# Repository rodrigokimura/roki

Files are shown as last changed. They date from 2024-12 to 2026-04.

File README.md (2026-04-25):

# RoKi

> An ergonomic, wireless, split mechanical keyboard — hardware, firmware and tooling in one repo.

**RoKi** (from the author's surname) is a custom, from-scratch split keyboard project. It covers the full stack: PCB design, 3D-printable case parts, CircuitPython firmware running on the [nice!nano v2](https://nicekeyboards.com/docs/nice-nano/) (wireless Bluetooth Low Energy controller), and a companion Python CLI / web UI / TUI to flash, configure and debug the board.

> ⚠️ **Status:** Work in progress. Breaking changes are expected.

---

## Features

- **Split layout** with BLE-based inter-half communication (no TRRS cable).
- **5 rows × 6 columns** per half, diode matrix.
- **Thumb cluster with analog thumbstick** (for pointer / scroll / layer control).
- **Rotary encoder** on each half.
- **Piezo buzzer** for audio feedback.
- **Layer system** with custom `layer_handler` (tap / hold / toggle commands).
- **HID support** for keyboard, mouse and consumer-control (media) keys, via `adafruit_hid`.
- **Per-side configuration** (primary / secondary) selected via environment.
- **Runtime calibration** of the analog thumbstick (deadzone, center, range).
- **Read-only filesystem toggle** at boot, driven by a hardware switch, so you can
  hot-swap between "keyboard mode" and "developer mode" without rebuilding firmware.

---

## Repository layout

```
roki/
├── roki/                    # Python package
│   ├── firmware/            # CircuitPython firmware (runs on nice!nano v2)
│   │   ├── boot.py          # Early boot: filesystem readonly switch
│   │   ├── code.py          # Main entry point, pin mapping
│   │   ├── kb.py            # Primary / Secondary keyboard classes
│   │   ├── keys.py          # HID key definitions and handlers
│   │   ├── layer_handler.py # Layer / Command system
│   │   ├── calibration.py   # Thumbstick calibration
│   │   ├── config.py        # Runtime config model + JSON loader
│   │   ├── service.py       # BLE service for half-to-half comms
│   │   ├── buzzer.py        # Audio feedback
│   │   ├── logging.py       # Color-coded adafruit_logging formatter
│   │   ├── params.py        # Env-based parameter singleton
│   │   └── config.json      # Default key map / layers
│   ├── cli/                 # Host-side CLI (typer)
│   │   ├── app.py           # `roki` command entry point
│   │   ├── utils.py         # Mount / unmount / lib install helpers
│   │   ├── file_management.py
│   │   ├── html_generator.py
│   │   └── logging.py
│   ├── tui/                 # Textual-based TUI key-map configurator
│   │   ├── app.py
│   │   ├── screens/
│   │   └── widgets/
│   └── templates/           # HTML templates for the web UI
├── tests/                   # pytest suite (firmware + cli)
├── kicad/roki/              # PCB design (schematic, layout, 3D step)
├── freecad/                 # Case, keycaps, thumbstick, encoder, etc.
├── conftest.py              # Global mocks for CircuitPython modules
└── pyproject.toml
```

---

## Hardware

| Item | Choice |
|---|---|
| Microcontroller | [nice!nano v2](https://nicekeyboards.com/docs/nice-nano/pinout-schematic/) (nRF52840, BLE) |
| Layout | Split, 5×6 + thumb cluster + encoder per half |
| Switches | MX-compatible, hotswap |
| Inter-half comms | Bluetooth Low Energy (custom GATT service) |
| Power | Li-Po, per-half power switch |
| Analog input | Thumbstick (X / Y + push) |

PCB sources live in [`kicad/roki/`](./kicad/roki/). Case, keycaps and mechanical parts live in [`freecad/`](./freecad/) as `.FCStd` files.

---

## Firmware (CircuitPython)

Runs on CircuitPython for nRF52840. The firmware is structured around a `Primary` / `Secondary` pair of keyboard halves:

- **Primary** holds the full config, scans its own matrix, talks HID over BLE to the host, and receives key events from the secondary over a custom BLE service.
- **Secondary** scans its matrix and forwards events to the primary.

The side is chosen at boot via the `IS_LEFT_SIDE` environment variable (or the `boot.py` switch pin), so the same code runs on both halves.

### Pin mapping

Defined in [`roki/firmware/code.py`](./roki/firmware/code.py):

```python
Roki(
    row_pins=("P0_24", "P1_00", "P0_11", "P1_04", "P1_06"),
    column_pins=("P0_09", "P0_10", "P1_11", "P1_13", "P1_15", "P0_02"),
    buzzer_pin="P0_06",
    thumb_stick_pins=("P0_22", "AIN7", "AIN5"),  # switch, X, Y
    encoder_pins=("P0_17", "P0_20"),
)
```

See the [nice!nano pinout & schematic](https://nicekeyboards.com/docs/nice-nano/pinout-schematic/) for reference.

### Boot-time write protection

`boot.py` reads pin `P0_22` on startup. When the switch is **open** the filesystem is mounted read-only (normal keyboard mode); when **closed**, read-write — useful for editing files over USB without your OS fighting CircuitPython.

---

## Host-side tooling

A `typer` CLI is installed as `roki`:

```sh
roki upload        # (alias: u)  Flash firmware + libs to the connected board
roki run           #             Launch the TUI key-map configurator
roki serve         #             Start the FastAPI + Jinja web config UI
roki generate      # (alias: g)  Generate static HTML / artifacts
roki config        #             Show / edit config.json
```

### Install

```sh
uv sync
```

(Uses [uv](https://docs.astral.sh/uv/) as the package manager; Python 3.12+.)

### Run the tests

```sh
uv run pytest
```

With coverage:

```sh
uv run pytest --cov=roki --cov-report=term
```

Current coverage: **88%** across ~2.3k lines of source with 109 tests.

### Run the web configurator locally (HTTPS)

```sh
# Generate self-signed certs once
openssl req -x509 -newkey rsa:2048 -keyout key.pem -out cert.pem -days 365

uv run roki serve
```

---

## Environment variables

Set in `roki/firmware/settings.toml` on the board, or via your shell for host-side runs:

| Variable | Default | Meaning |
|---|---|---|
| `IS_LEFT_SIDE`  | `1` | `1` for primary (left), `0` for secondary |
| `DEBUG` | `0` | `1` enables the stream logger |
| `LOG_LEVEL` | `0` | Standard logging levels (10 = DEBUG, etc.)  |

---

## Development workflow

This repo uses [commitizen](https://commitizen-tools.github.io/commitizen/) for [Conventional Commits](https://www.conventionalcommits.org/) and [ruff](https://docs.astral.sh/ruff/) for linting / import sorting.

```sh
uv run cz commit            # interactive commit
uv run ruff check --fix .   # lint + autofix
uv run ruff format .        # format
```

Pre-commit hooks are configured in [`.pre-commit-config.yaml`](./.pre-commit-config.yaml).

---

## License

[MIT](./LICENSE) © Rodrigo Eiti Kimura

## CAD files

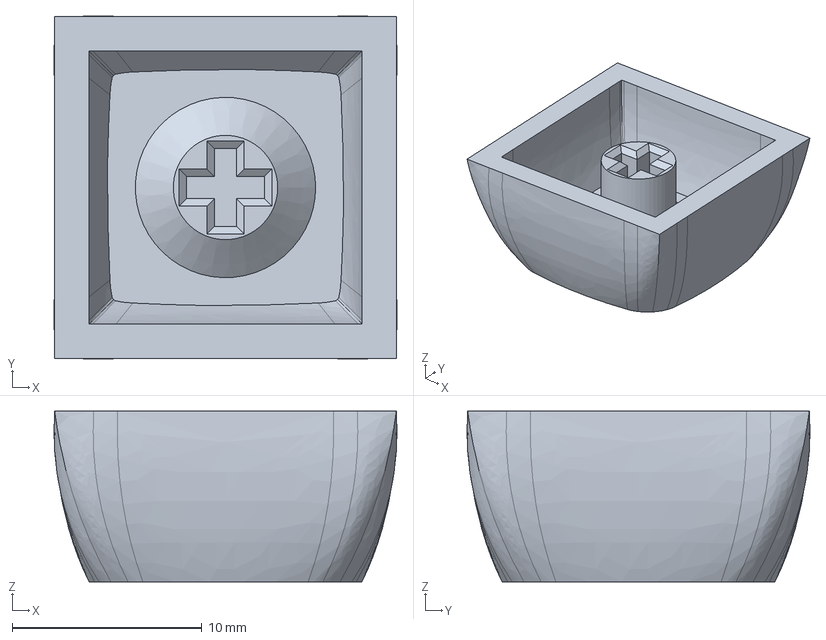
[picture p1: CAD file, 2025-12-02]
freecad/keycap.FCStd
18.1 x 18.1 x 9.00 mm

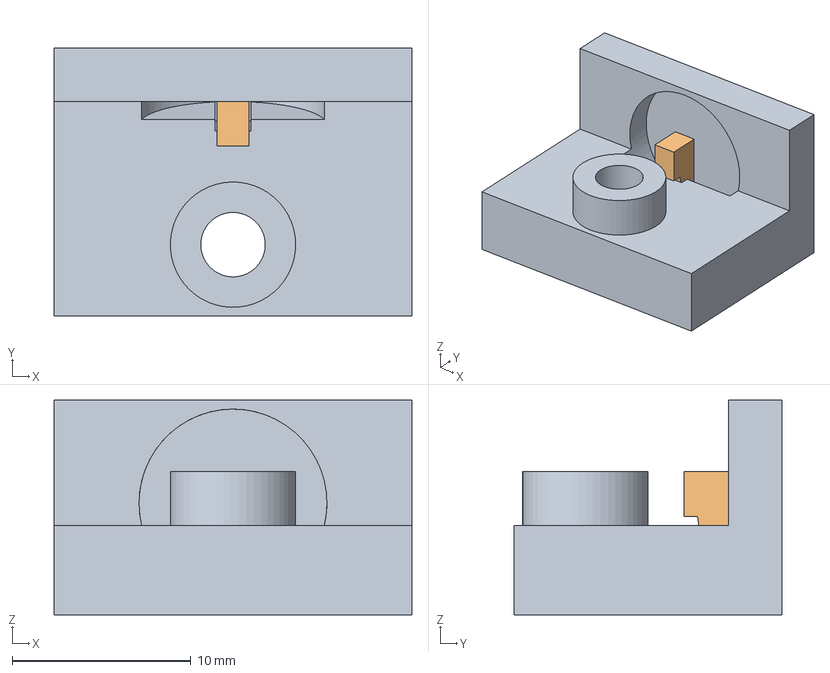
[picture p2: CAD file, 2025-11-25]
freecad/vertical_magnet_wedge_test.FCStd
20.0 x 15.0 x 12.0 mm
hole_test
wedge

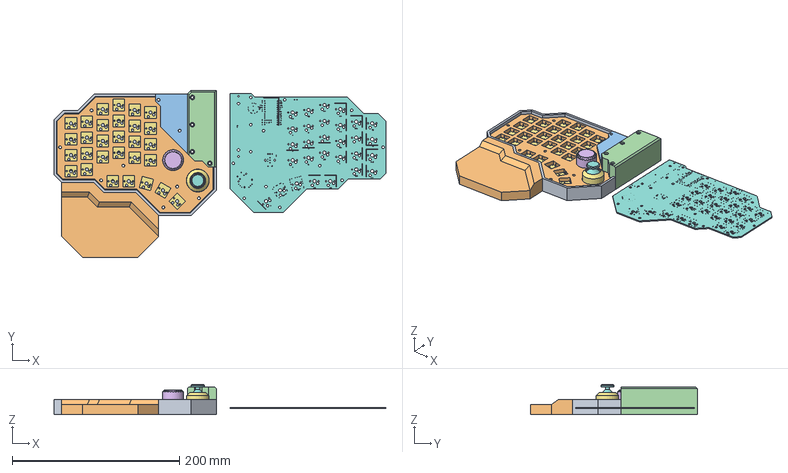
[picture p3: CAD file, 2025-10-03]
freecad/roki.FCStd
397.4 x 199.8 x 36.0 mm
roki_silkscreen
roki_silkscreen001
roki_silkscreen002
roki_silkscreen003
roki_silkscreen004
roki_silkscreen005
roki_silkscreen006
roki_silkscreen007
roki_silkscreen008
roki_silkscreen009
roki_silkscreen010
roki_silkscreen011
roki_silkscreen012
roki_silkscreen013
roki_silkscreen014
roki_silkscreen015
roki_silkscreen016
roki_silkscreen017
roki_silkscreen018
roki_silkscreen019
roki_silkscreen020
roki_silkscreen021
roki_silkscreen022
roki_silkscreen023
roki_silkscreen024
roki_silkscreen025
roki_silkscreen026
roki_silkscreen027
roki_silkscreen028
roki_silkscreen029
roki_silkscreen030
roki_silkscreen031
roki_silkscreen032
roki_silkscreen033
roki_silkscreen034
roki_silkscreen035
roki_silkscreen036
roki_silkscreen037
roki_silkscreen038
roki_silkscreen039
roki_silkscreen040
roki_silkscreen041
roki_silkscreen042
roki_silkscreen043
roki_silkscreen044
roki_silkscreen045
roki_silkscreen046
roki_silkscreen047
roki_silkscreen048
roki_silkscreen049
roki_silkscreen050
roki_silkscreen051
roki_silkscreen052
roki_silkscreen053
roki_silkscreen054
roki_silkscreen055
roki_silkscreen056
roki_silkscreen057
roki_silkscreen058
roki_silkscreen059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

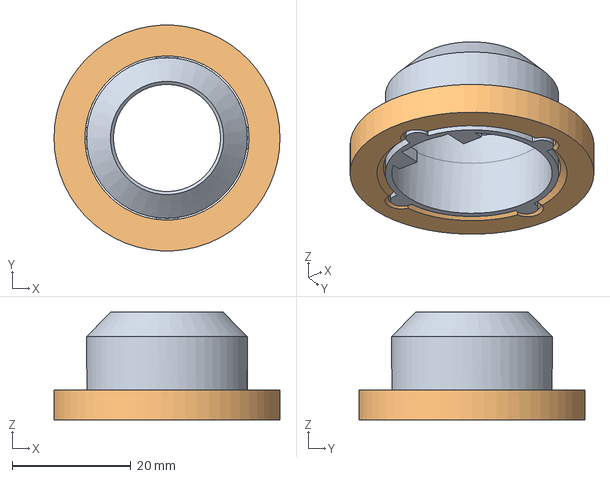
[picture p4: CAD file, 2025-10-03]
freecad/thumb_stick.FCStd
38.0 x 37.9 x 18.1 mm
cover
hole_fit_test

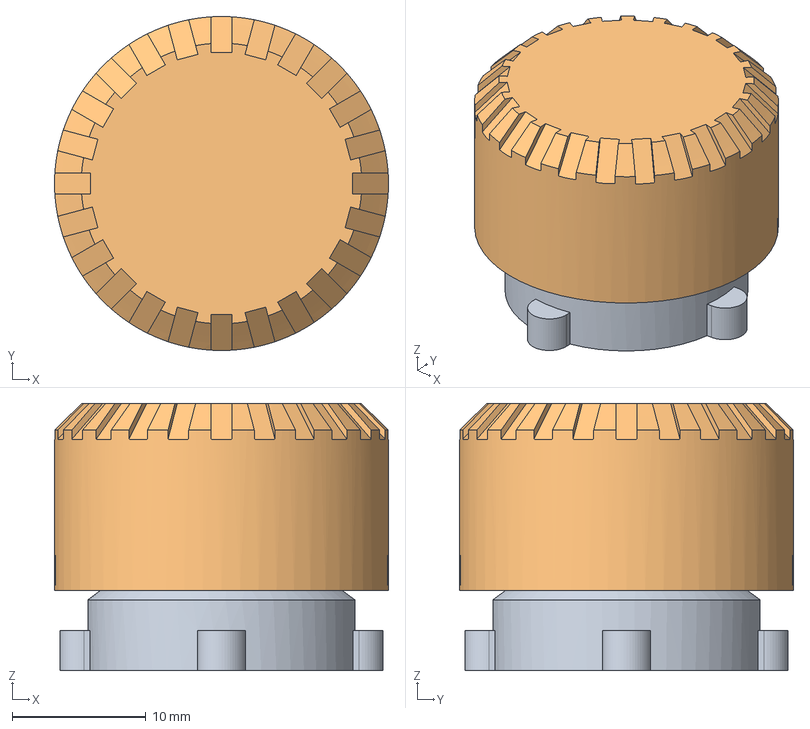
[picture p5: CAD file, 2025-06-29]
freecad/encoder.FCStd
25.0 x 25.0 x 20.0 mm
cover
knob

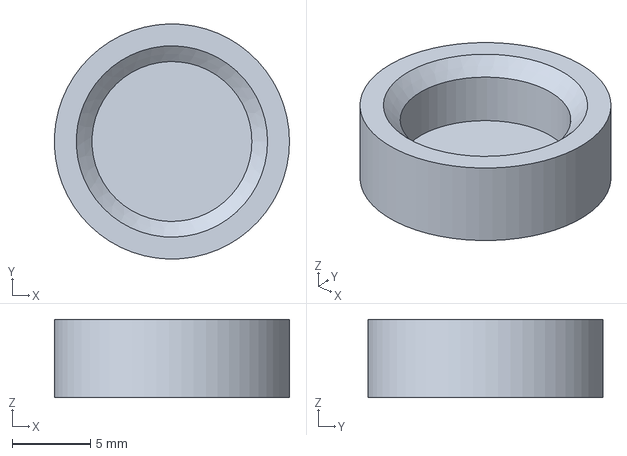
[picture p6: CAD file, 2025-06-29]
freecad/magnet_fit_test.FCStd
15.0 x 15.0 x 5.00 mm

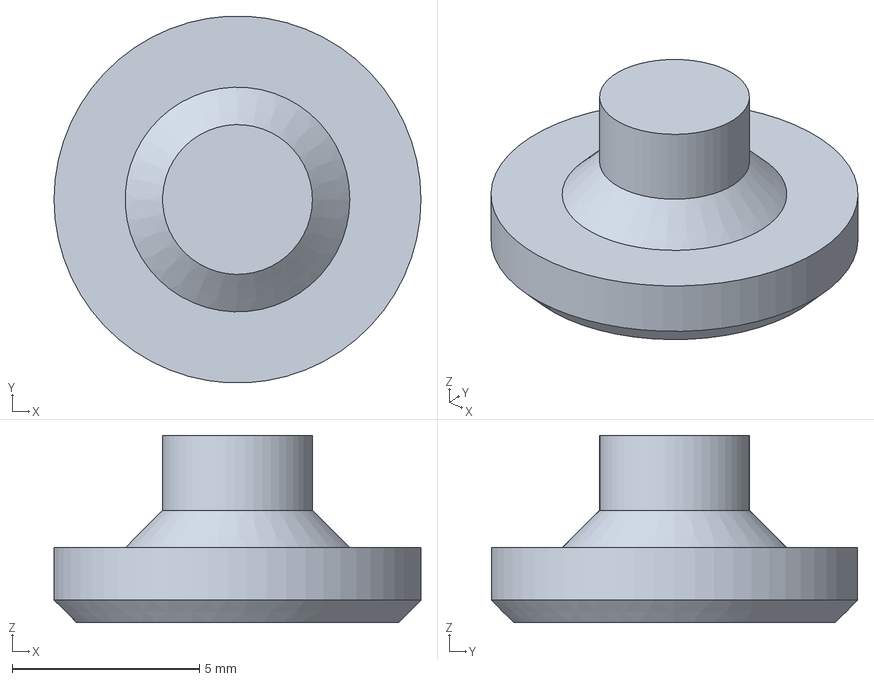
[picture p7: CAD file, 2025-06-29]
freecad/magnet_spacer.FCStd
9.80 x 9.79 x 5.00 mm

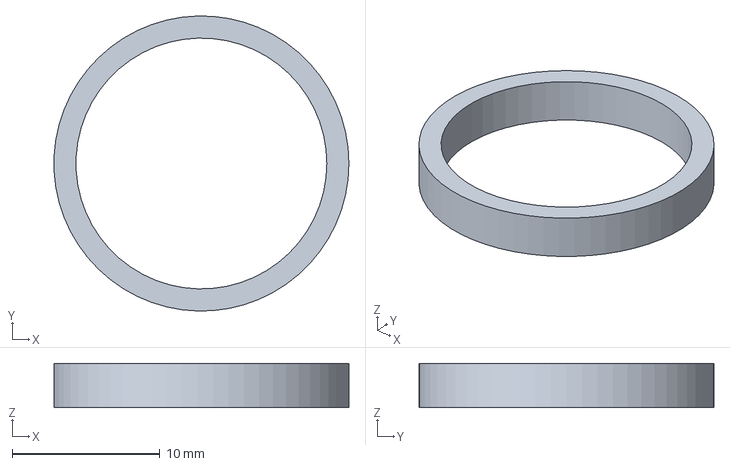
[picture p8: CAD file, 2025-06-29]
freecad/encoder_fit_test.FCStd
20.0 x 20.0 x 3.00 mm

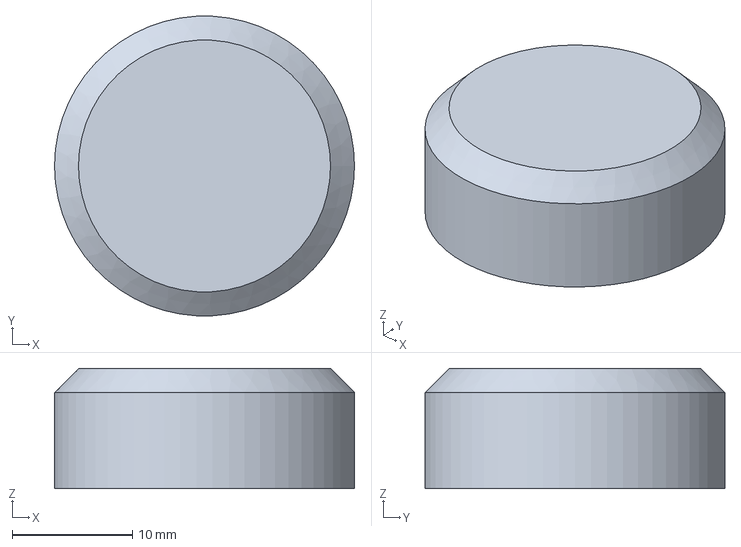
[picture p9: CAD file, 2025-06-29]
freecad/knob.FCStd
25.0 x 25.0 x 10.0 mm

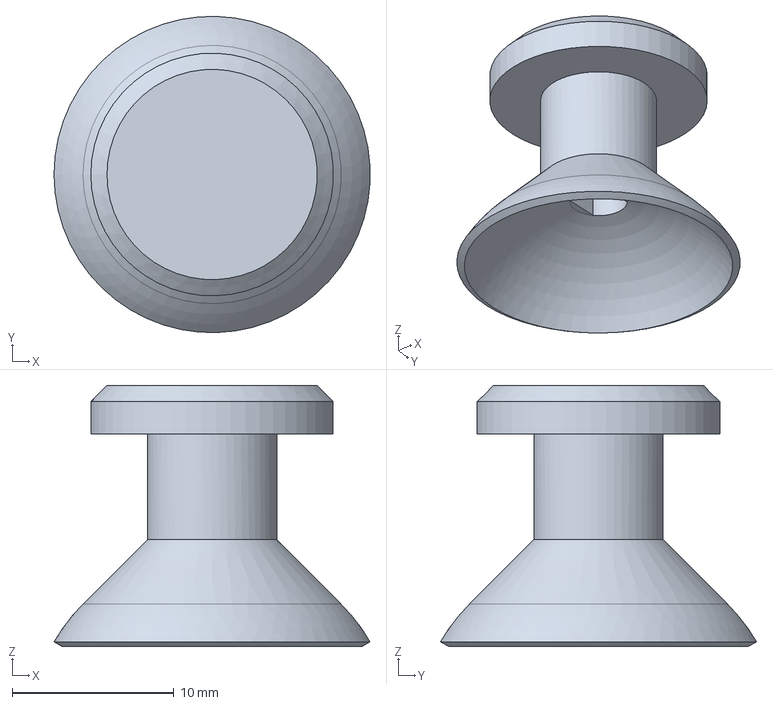
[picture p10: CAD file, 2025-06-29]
freecad/thumb_stick_cap.FCStd
19.5 x 19.5 x 16.2 mm

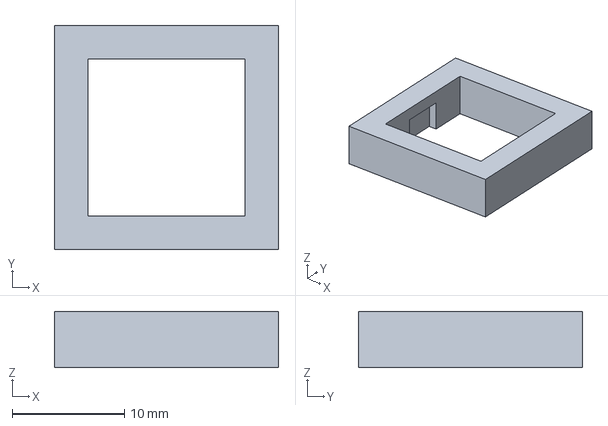
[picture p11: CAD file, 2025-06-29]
freecad/switch_pocket.FCStd
20.0 x 20.0 x 5.00 mm

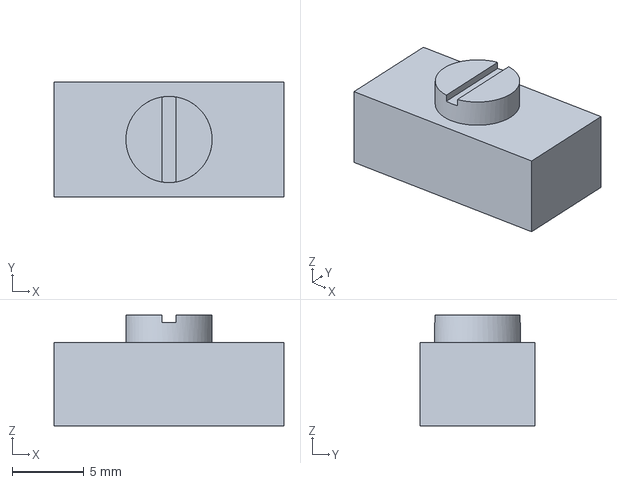
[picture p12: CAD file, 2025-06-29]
freecad/power_switch.FCStd
16.0 x 8.00 x 7.70 mm

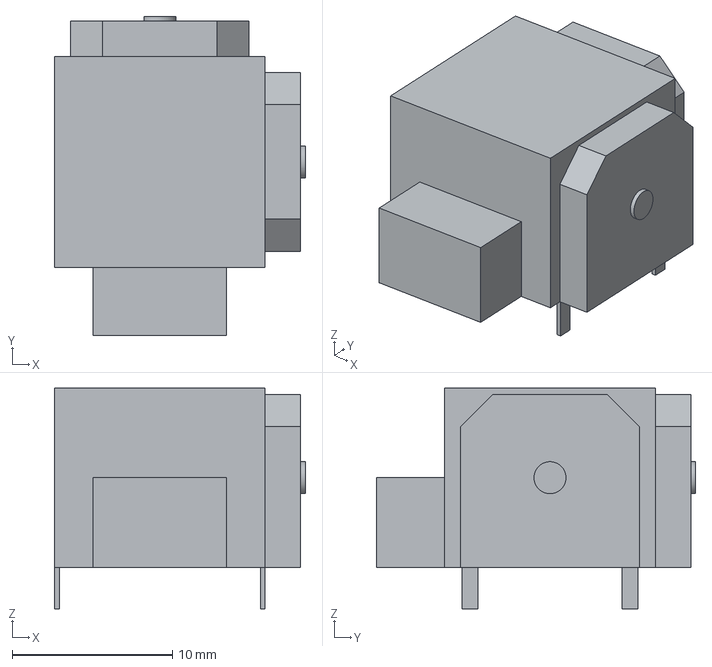
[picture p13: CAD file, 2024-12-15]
freecad/thumb_stick-Body.step
15.7 x 19.9 x 13.8 mm

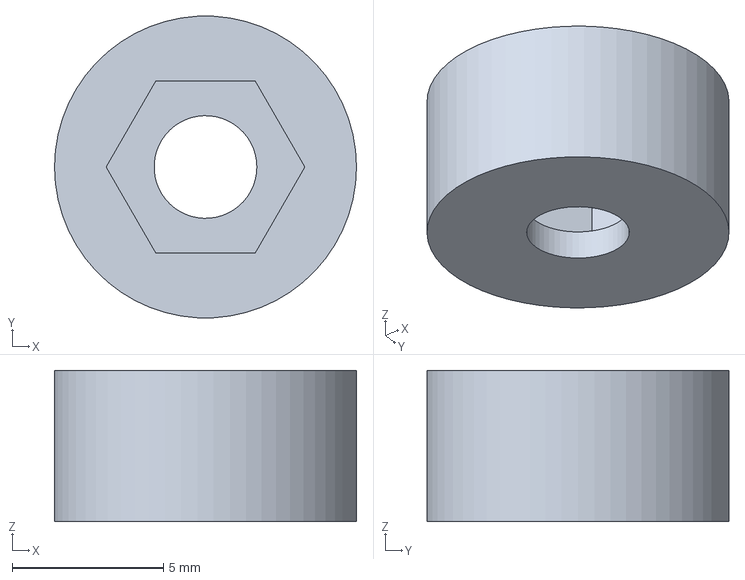
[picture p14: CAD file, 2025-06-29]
freecad/nut_fit_test.FCStd
10.0 x 9.99 x 5.00 mm

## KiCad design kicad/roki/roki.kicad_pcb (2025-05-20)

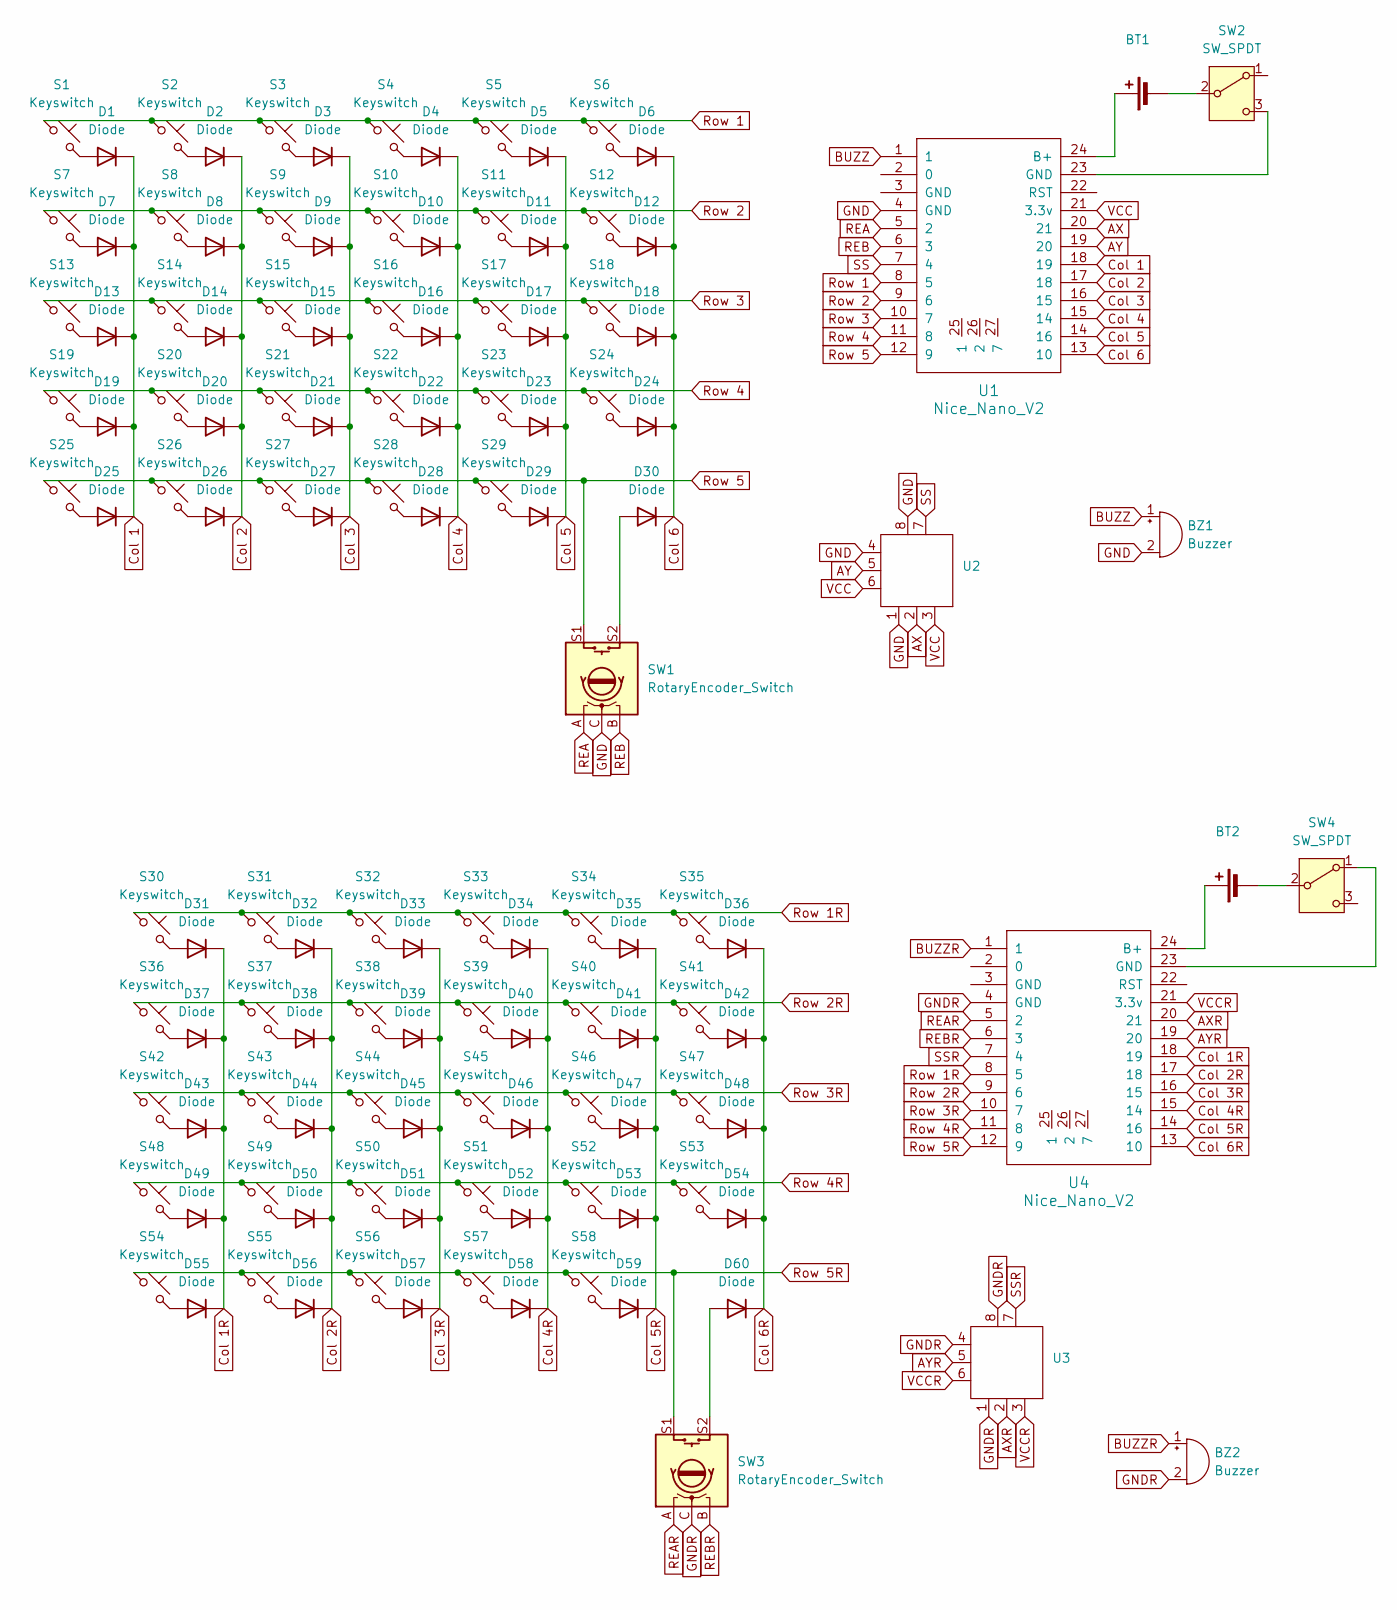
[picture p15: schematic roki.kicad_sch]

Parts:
BT1, BT2: Battery_Cell; BatteryHolder_MPD_BH-18650-PC2
BZ1, BZ2: Buzzer; Buzzer_TDK_PS1240P02BT_D12.2mm_H6.5mm
D1, D2, D3, D4, D5, D6, D7, D8, D9, D10, D11, D12, D13, D14, D15, D16, D17, D18, D19, D20, D21, D22, D23, D24, D25, D26, D27, D28, D29, D30, D31, D32, D33, D34, D35, D36, D37, D38, D39, D40, D41, D42, D43, D44, D45, D46, D47, D48, D49, D50, D51, D52, D53, D54, D55, D56, D57, D58, D59, D60: Diode; Diode_SOD-123
S1, S2, S3, S4, S5, S6, S7, S8, S9, S10, S11, S12, S13, S14, S15, S16, S17, S18, S19, S20, S21, S22, S23, S24, S25, S26, S27, S28, S29, S30, S31, S32, S33, S34, S35, S36, S37, S38, S39, S40, S41, S42, S43, S44, S45, S46, S47, S48, S49, S50, S51, S52, S53, S54, S55, S56, S57, S58: Keyswitch; Hotswap_MX_1.00u
SW1, SW3: RotaryEncoder_Switch; RotaryEncoder_Alps_EC11E-Switch_Vertical_H20mm
SW2, SW4: SW_SPDT; SW_SPDT_PCM12
U1, U4: Nice_Nano_V2
U2, U3: thumb_stick

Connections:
AX: U1.20 (21), U2.2
AXR: U3.2, U4.20 (21)
AY: U1.19 (20), U2.5
AYR: U3.5, U4.19 (20)
BUZZ: BZ1.1 (+), U1.1
BUZZR: BZ2.1 (+), U4.1
Col 1: D1.1 (K), D7.1 (K), D13.1 (K), D19.1 (K), D25.1 (K), U1.18 (19)
Col 1R: D31.1 (K), D37.1 (K), D43.1 (K), D49.1 (K), D55.1 (K), U4.18 (19)
Col 2: D2.1 (K), D8.1 (K), D14.1 (K), D20.1 (K), D26.1 (K), U1.17 (18)
Col 2R: D32.1 (K), D38.1 (K), D44.1 (K), D50.1 (K), D56.1 (K), U4.17 (18)
Col 3: D3.1 (K), D9.1 (K), D15.1 (K), D21.1 (K), D27.1 (K), U1.16 (15)
Col 3R: D33.1 (K), D39.1 (K), D45.1 (K), D51.1 (K), D57.1 (K), U4.16 (15)
Col 4: D4.1 (K), D10.1 (K), D16.1 (K), D22.1 (K), D28.1 (K), U1.15 (14)
Col 4R: D34.1 (K), D40.1 (K), D46.1 (K), D52.1 (K), D58.1 (K), U4.15 (14)
Col 5: D5.1 (K), D11.1 (K), D17.1 (K), D23.1 (K), D29.1 (K), U1.14 (16)
Col 5R: D35.1 (K), D41.1 (K), D47.1 (K), D53.1 (K), D59.1 (K), U4.14 (16)
Col 6: D6.1 (K), D12.1 (K), D18.1 (K), D24.1 (K), D30.1 (K), U1.13 (10)
Col 6R: D36.1 (K), D42.1 (K), D48.1 (K), D54.1 (K), D60.1 (K), U4.13 (10)
GND: BZ1.2 (-), SW1.C, U1.4 (GND), U2.1, U2.4, U2.8
GNDR: BZ2.2 (-), SW3.C, U3.1, U3.4, U3.8, U4.4 (GND)
unnamed: BT1.1 (+), U1.24 (B+)
unnamed: BT1.2 (-), SW2.2 (B)
unnamed: BT2.1 (+), U4.24 (B+)
unnamed: BT2.2 (-), SW4.2 (B)
unnamed: D1.2 (A), S1.2
unnamed: D2.2 (A), S2.2
unnamed: D3.2 (A), S3.2
unnamed: D4.2 (A), S4.2
unnamed: D5.2 (A), S5.2
unnamed: D6.2 (A), S6.2
unnamed: D7.2 (A), S7.2
unnamed: D8.2 (A), S8.2
unnamed: D9.2 (A), S9.2
unnamed: D10.2 (A), S10.2
unnamed: D11.2 (A), S11.2
unnamed: D12.2 (A), S12.2
unnamed: D13.2 (A), S13.2
unnamed: D14.2 (A), S14.2
unnamed: D15.2 (A), S15.2
unnamed: D16.2 (A), S16.2
unnamed: D17.2 (A), S17.2
unnamed: D18.2 (A), S18.2
unnamed: D19.2 (A), S19.2
unnamed: D20.2 (A), S20.2
unnamed: D21.2 (A), S21.2
unnamed: D22.2 (A), S22.2
unnamed: D23.2 (A), S23.2
unnamed: D24.2 (A), S24.2
unnamed: D25.2 (A), S25.2
unnamed: D26.2 (A), S26.2
unnamed: D27.2 (A), S27.2
unnamed: D28.2 (A), S28.2
unnamed: D29.2 (A), S29.2
unnamed: D30.2 (A), SW1.S2
unnamed: D31.2 (A), S30.2
unnamed: D32.2 (A), S31.2
unnamed: D33.2 (A), S32.2
unnamed: D34.2 (A), S33.2
unnamed: D35.2 (A), S34.2
unnamed: D36.2 (A), S35.2
unnamed: D37.2 (A), S36.2
unnamed: D38.2 (A), S37.2
unnamed: D39.2 (A), S38.2
unnamed: D40.2 (A), S39.2
unnamed: D41.2 (A), S40.2
unnamed: D42.2 (A), S41.2
unnamed: D43.2 (A), S42.2
unnamed: D44.2 (A), S43.2
unnamed: D45.2 (A), S44.2
unnamed: D46.2 (A), S45.2
unnamed: D47.2 (A), S46.2
unnamed: D48.2 (A), S47.2
unnamed: D49.2 (A), S48.2
unnamed: D50.2 (A), S49.2
unnamed: D51.2 (A), S50.2
unnamed: D52.2 (A), S51.2
unnamed: D53.2 (A), S52.2
unnamed: D54.2 (A), S53.2
unnamed: D55.2 (A), S54.2
unnamed: D56.2 (A), S55.2
unnamed: D57.2 (A), S56.2
unnamed: D58.2 (A), S57.2
unnamed: D59.2 (A), S58.2
unnamed: D60.2 (A), SW3.S2
unnamed: SW2.3 (C), U1.23 (GND)
unnamed: SW4.1 (A), U4.23 (GND)
REA: SW1.A, U1.5 (2)
REAR: SW3.A, U4.5 (2)
REB: SW1.B, U1.6 (3)
REBR: SW3.B, U4.6 (3)
Row 1: S1.1, S2.1, S3.1, S4.1, S5.1, S6.1, U1.8 (5)
Row 1R: S30.1, S31.1, S32.1, S33.1, S34.1, S35.1, U4.8 (5)
Row 2: S7.1, S8.1, S9.1, S10.1, S11.1, S12.1, U1.9 (6)
Row 2R: S36.1, S37.1, S38.1, S39.1, S40.1, S41.1, U4.9 (6)
Row 3: S13.1, S14.1, S15.1, S16.1, S17.1, S18.1, U1.10 (7)
Row 3R: S42.1, S43.1, S44.1, S45.1, S46.1, S47.1, U4.10 (7)
Row 4: S19.1, S20.1, S21.1, S22.1, S23.1, S24.1, U1.11 (8)
Row 4R: S48.1, S49.1, S50.1, S51.1, S52.1, S53.1, U4.11 (8)
Row 5: S25.1, S26.1, S27.1, S28.1, S29.1, SW1.S1, U1.12 (9)
Row 5R: S54.1, S55.1, S56.1, S57.1, S58.1, SW3.S1, U4.12 (9)
SS: U1.7 (4), U2.7
SSR: U3.7, U4.7 (4)
VCC: U1.21 (3.3v), U2.3, U2.6
VCCR: U3.3, U3.6, U4.21 (3.3v)

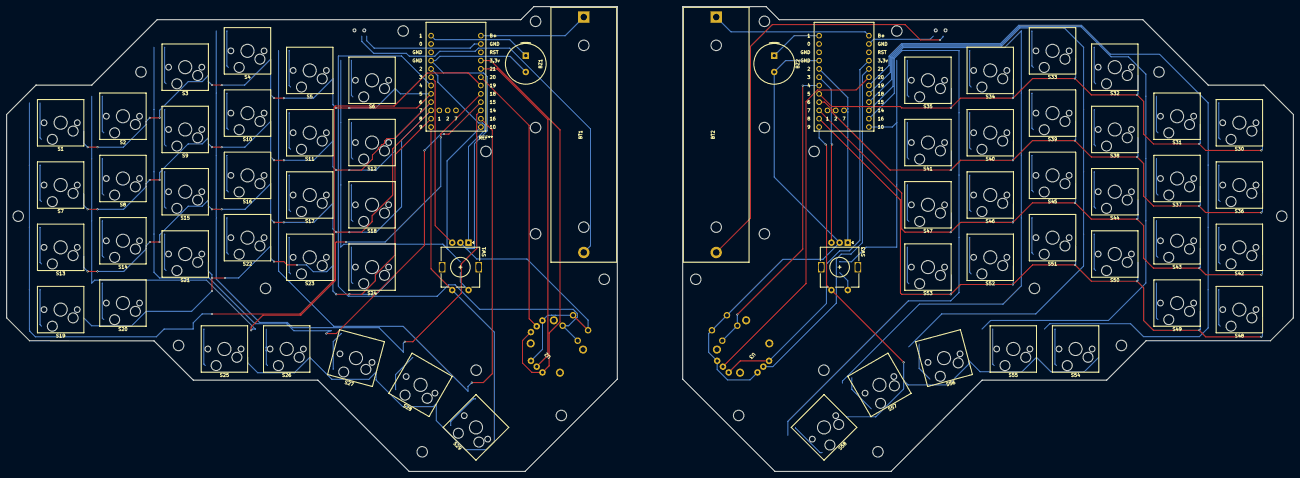
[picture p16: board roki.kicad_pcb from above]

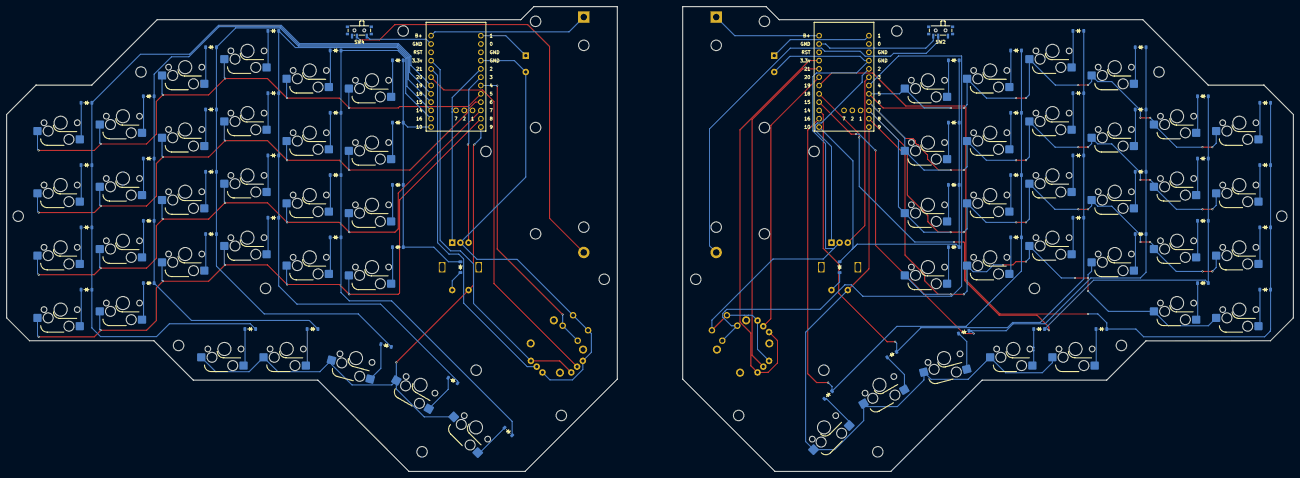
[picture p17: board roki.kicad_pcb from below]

Board: 2 copper layers, 393.6 x 142.2 mm, 130 parts (62 on the bottom side), 104 nets.

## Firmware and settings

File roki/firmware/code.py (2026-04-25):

import board

from roki.firmware import logging
from roki.firmware.params import Params

Params.from_env()

logger = logging.getLogger(__name__)


def main():
    from roki.firmware.config import Config
    from roki.firmware.kb import Primary, Secondary

    # pin mapping for the nice!nano
    config = Config.read()
    roki = (Primary if config.is_left_side else Secondary)(
        config=config,
        row_pins=("P0_24", "P1_00", "P0_11", "P1_04", "P1_06"),
        column_pins=("P0_09", "P0_10", "P1_11", "P1_13", "P1_15", "P0_02"),
        buzzer_pin="P0_06",
        thumb_stick_pins=("P0_22", "AIN7", "AIN5"),
        encoder_pins=("P0_17", "P0_20"),
        encoder_divisor=4,
        columns_to_anodes=False,
        interval=0.001,
        max_events=5,
        connection_interval=7.5,
    )
    roki.run()


if __name__ == "__main__":
    logger.debug("Available attrs for board: ")
    logger.debug(str(dir(board)))

    logger.info("Board ID: " + board.board_id)

    main()

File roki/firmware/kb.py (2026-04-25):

import _bleio
import board
import rotaryio
from adafruit_ble import BLEConnection, BLERadio
from adafruit_ble.advertising import Advertisement
from adafruit_ble.advertising.standard import ProvideServicesAdvertisement
from adafruit_ble.services.standard.device_info import DeviceInfoService
from analogio import AnalogIn
from digitalio import DigitalInOut, Direction, Pull
from keypad import KeyMatrix
from pwmio import PWMOut

from roki.firmware import logging
from roki.firmware.buzzer import Buzzer
from roki.firmware.calibration import BaseCalibration, Calibration
from roki.firmware.config import Config
from roki.firmware.keys import BaseKey, LayerHandlerKey
from roki.firmware.layer_handler import OnPressExtrasCommand
from roki.firmware.messages import ENCODER, KEY, THUMB_STICK
from roki.firmware.service import RokiService
from roki.firmware.utils import (
    Cycle,
    Debouncer,
    Loop,
    decode_float,
    encode_float,
)

logger = logging.getLogger(__name__)


class Roki:
    def __init__(
        self,
        config: Config,
        row_pins: tuple[str, ...],
        column_pins: tuple[str, ...],
        buzzer_pin: str,
        thumb_stick_pins: tuple[str, str, str],
        encoder_pins: tuple[str, str],
        encoder_divisor: int = 4,
        columns_to_anodes: bool = False,
        interval: float = 0.01,
        max_events: int = 5,
        connection_interval: float = 7.5,
        calibration_class: type[BaseCalibration] = Calibration,
        max_iterations_main_loop: int = 0,
        max_iterations_ble: int = 0,
    ):
        self.buzzer = Buzzer(
            PWMOut(getattr(board, buzzer_pin), variable_frequency=True)
        )
        self.row_count = len(row_pins)
        self.col_count = len(column_pins)
        a, b = encoder_pins
        self.encoder = rotaryio.IncrementalEncoder(
            getattr(board, a), getattr(board, b), encoder_divisor
        )

        b, x, y = thumb_stick_pins

        thumb_stick_button = DigitalInOut(getattr(board, b))
        thumb_stick_button.direction = Direction.INPUT
        thumb_stick_button.pull = Pull.UP

        self.thumb_stick_x = AnalogIn(getattr(board, x))
        self.thumb_stick_y = AnalogIn(getattr(board, y))

        self.calibration = calibration_class(
            thumb_stick_button,
            self.thumb_stick_x,
            self.thumb_stick_y,
            self.buzzer,
        )

        self.encoder_position = Debouncer(self.encoder.position)
        self.connection_interval = connection_interval
        self.key_matrix = KeyMatrix(
            row_pins=tuple(getattr(board, pin) for pin in row_pins),
            column_pins=tuple(getattr(board, pin) for pin in column_pins),
            columns_to_anodes=columns_to_anodes,
            interval=interval,
            max_events=max_events,
        )
        self.config: Config = config
        self.ble = BLERadio()
        self.mouse_speed = 10
        self.max_iterations_main_loop = max_iterations_main_loop
        self.max_iterations_ble = max_iterations_ble

    def run(self):
        logger.info("Preparing...")

        self.start_calibration()

        logger.info("Running...")
        self.notify_main_loop_start()
        self.run_main_loop()

    def notify_main_loop_start(self):
        self.buzzer.play_notes(
            (
                ("C3", 1),
                ("D3", 1),
                ("E3", 2),
            ),
            0.15,
        )

    def notify_error(self):
        self.buzzer.play_notes(
            (
                ("C1", 2),
                ("", 1),
                ("C1", 4),
            ),
            0.05,
        )

    def run_main_loop(self): ...

    def start_calibration(self):
        self.calibration.start()

    def disconnect(self):
        if self.ble.connected:
            logger.info("Already connected. Disconnecting...")
            for conn in self.ble.connections:
                if conn:
                    conn.disconnect()


class Primary(Roki):
    def run_main_loop(self):
        from roki.firmware.keys import hid

        DeviceInfoService(
            software_revision="0.1.0",
            manufacturer="Adafruit Industries",
        )
        if hid is None:
            raise RuntimeError("HID Service not started")

        advertisement = ProvideServicesAdvertisement(hid)
        # Advertise as "Keyboard" (0x03C1) icon when pairing
        # https://www.bluetooth.com/specifications/assigned-numbers/
        advertisement.appearance = 961
        scan_response = Advertisement()
        scan_response.complete_name = "Roki"

        self.ble.name = "Roki"

        self.disconnect()

        self.peripheral_conn = self.connect_to_peripheral_side(self.connection_interval)
        self._notify_peripheral_connection()

        logger.info("Advertising...")
        self.ble.start_advertising(advertisement, scan_response)
        self.buffer = bytearray(4)
        self.current_counter = 0

        for _ in Loop(self.max_iterations_main_loop).iterate():
            for _ in Loop(
                self.max_iterations_ble,
                lambda: self.ble.connected,
            ).iterate():
                pass

            for _ in Loop(
                self.max_iterations_ble,
                lambda: not self.ble.connected,
            ).iterate():
                self.process_primary_keys()
                if self.config.extras:
                    self.process_primary_encoder()
                    self.process_primary_thumb_stick()

                if self.peripheral_conn.connected:
                    counter, message_id, payload_1, payload_2 = self.get_message()

                    if counter and self.current_counter != counter:
                        self.current_counter = counter
                        self._handle_message(message_id, payload_1, payload_2)
                else:
                    self.peripheral_conn = self.connect_to_peripheral_side(
                        self.connection_interval
                    )

            # disconnected
            self.notify_error()
            self.ble.start_advertising(advertisement)

    def _notify_peripheral_connection(self):
        self.buzzer.play_notes(
            (
                ("C3", 2),
                ("", 1),
                ("D3", 4),
            ),
            0.05,
        )

    def get_message(self) -> tuple[int, int, int, int]:
        service: RokiService = self.peripheral_conn[RokiService]  # type: ignore
        return service.readinto(self.buffer)
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

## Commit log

2024-09-12 fix(firmware): protect against exception
    [config.py]
2024-09-18 fix(firmware): reimplement layers using central-peripheral connection
    [config.py, keys.py, manager.py]
2024-10-09 feat(firmware): improve connection flow
2024-10-09 fix(cli): copy file after its update
    [app.py]
2024-11-05 fix(cli): get circuitpython libs from correct files
    [app.py]
2024-11-09 feat(firmware): add encoder feature
2024-11-09 docs(readme): add pinout and schematic link
2024-12-08 fix(cli): change options for upload command
    [app.py]
2024-12-15 feat(kicad): add kicak files
    [roki.kicad_pcb, roki.kicad_sch]
2024-12-15 feat(freecad): add freecad files
    [thumb_stick-Body.step, thumb_stick.FCStd]
2024-12-25 feat(firmware): add calibration algorithm
2025-01-09 fix(firmware): avoid initialization of used pin
    [calibration.py, code.py, kb.py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]
2025-01-09 fix(kicad): fix thumb stick pin schematics
    [roki.kicad_sch]
2025-01-23 feat(firmware): write calibration data
2025-01-29 feat(cli): improve upload command to keep calibration config
2025-01-29 fix(firmware): adjust condition for skipping action
    [kb.py]
2025-02-01 test: add missing tests
    [keys.py, layer_handler.py, test_keys.py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]
2025-02-03 fix(firmware): add null check
    [kb.py]
2025-02-04 test: add missing test cases
    [test_config.py, test_utils.py, utils.py]
2025-02-11 feat(kicad): add right side
    [roki.kicad_pcb, roki.kicad_sch]
2025-03-15 feat(firmware): add buzzer class
    [buzzer.py]
2025-03-18 feat(kicad): update pcb
    [roki.kicad_pcb, roki.kicad_sch]
2025-03-19 feat(kicad): pin components
    [roki.kicad_pcb]
2025-03-25 feat(kicad): update files
    [roki.kicad_pcb]
2025-05-20 feat(kicad): export pcb model
2025-05-20 feat(freecad): create main model
    [roki.FCStd]
2025-06-29 feat(freecad): update models
    [encoder.FCStd, encoder_fit_test.FCStd, knob.FCStd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]
2025-06-29 fix(firmware): use same config instance
    [kb.py]
2025-11-16 feat(freecad): udpate models
    [vertical_magnet_wedge_test.FCStd]
2025-12-02 Add keycap model
    [keycap.FCStd]
2025-12-09 feat(firmware): allow to disable thumb stick and encoder
2026-02-24 test(firmware): fix keywrapper test
    [test_keys.py]
2026-03-26 fix(firmware): fix key order when reading on secondary side
    [config.py, kb.py]
2026-04-25 test: add tests for boot, cli logging and firmware logging (#68)
    - rewrite tests/firmware/test_boot.py to cover Params.from_env,
    switch pin configuration, read-only vs read-write remount,
    RuntimeError handling and switch deinit (8 tests)
    - add tests/cli/test_logging.py covering format_by_level,
    LevelBasedFormatter and configure_logging (11 tests)
    - add tests/firmware/test_logging.py covering format_by_level,
    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
2026-04-25 style: organize imports with ruff (#69)
    Applied `ruff check --select I --fix .` across the codebase, sorting
    and grouping imports in 12 Python files (4 under `roki/` and 8 under
    `tests/`). No behavioral changes; all 109 tests still pass.
    [code.py, config.py, kb.py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]
2026-04-25 docs: rewrite README with full project description (#70)
    Expand the README from a near-empty stub into a proper project overview
    covering:
    - what RoKi is (split BLE keyboard, full-stack project)
    - feature list
    - repository layout
    - hardware summary
    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
